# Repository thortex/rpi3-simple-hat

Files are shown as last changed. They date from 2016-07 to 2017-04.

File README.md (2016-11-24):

# 40-pin RPis Simple Hats

Simple Hats for 40-pin Raspbery Pi models.

## GPIO_LCD_HD44780

This hat includes the following devices:

1. three push switches.
2. three LEDs.
3. five DIP switches.
4. four I2C bus pin headers.
5. one HD44780-compatible LCD interface.
6. one CPU fan connector.
7. one UART bus pin header.

## HW-PWMx2
 
This hat includes the following interfaces:

1. Two hardware PWM controlled servo motor connectors.
2. A CPU fan connector.

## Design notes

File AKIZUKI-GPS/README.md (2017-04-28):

# 秋月電子通商製 GPS の接続方法

秋月電子通商より発売されている みちびき対応 GPS を
取り付ける方法を解説します（簡単です）。

## 必要な部材

必要な部材は本体とケーブルの二つだけです。

* [本体](http://akizukidenshi.com/catalog/g/gK-09991/)
* [ケーブル](http://akizukidenshi.com/catalog/g/gC-09731/)

## 初期設定

* ※ GPSを接続する前に行います。
* UART (serail) を有効にする必要があります。
* ※ OnChip Bluetooth の有無により、設定が異なります。

### 前提条件

Kernel は 4.4.x 〜 4.9.x 程度と仮定します。
パッケージ類は最新であると仮定します。

     $ sudo apt-get update
     $ sudo apt-get upgrade
     $ sudo rpi-update

### OnChip Bluetooth 未搭載モデル

UART (serial) を raspi-config で有効にする必要があります。

    $ sudo raspi-config

「5 Interfacing Options」を選択します。

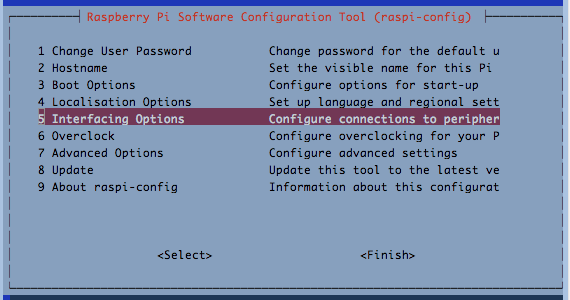
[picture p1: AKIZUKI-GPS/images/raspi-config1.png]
設定1


「P6 Serial」を選択します。

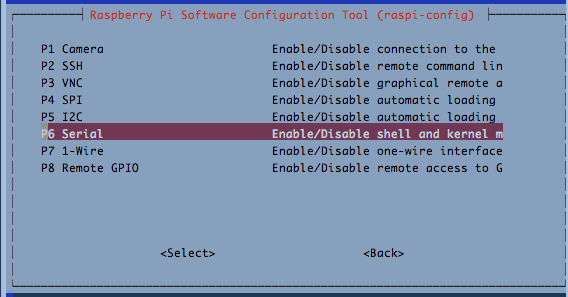
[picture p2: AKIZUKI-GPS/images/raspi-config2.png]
設定2


「Would you like a login shell to be acessible over serial?」と聞かれますが、
コンソールログインは使用しませんので「いいえ」を選択します。
「はい」を選択してしまうと、GPS側にコンソール（起動ログ等の）文字列が出力
されてしまい、誤動作する可能性があります。

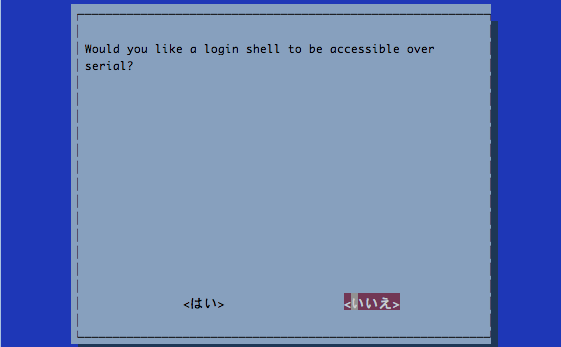
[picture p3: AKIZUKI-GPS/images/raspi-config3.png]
設定3


「Would you like to serial port hardware to be enabled?」と聞かれますので、
「はい」を選択します。

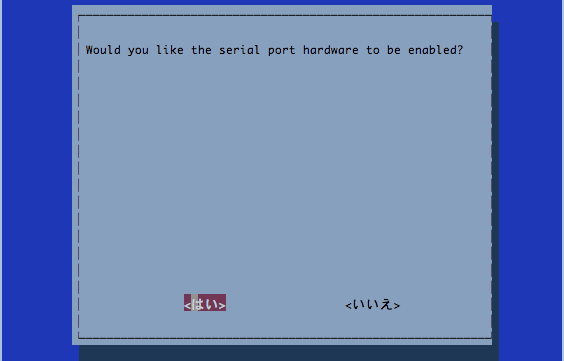
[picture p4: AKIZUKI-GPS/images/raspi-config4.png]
設定4


確認画面が表示されるので、「了解」を選択します。

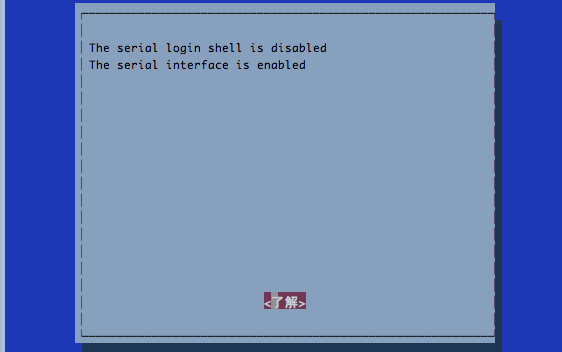
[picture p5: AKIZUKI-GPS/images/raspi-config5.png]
設定5


「Finish」を選択し、raspi-config を終了します。

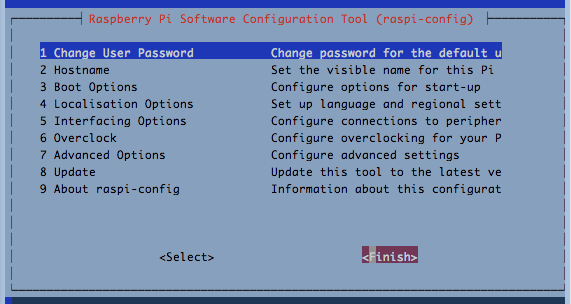
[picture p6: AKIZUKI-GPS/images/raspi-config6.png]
設定6


再起動を促されますが、一度電源を切り、GPS を接続します。

     $ sudo poweroff

### OnChip Bluetooth 搭載モデル (RPi3, RPi0W)

OnChip Bluetooth がついている RPi3, RPi0W は Bluetooth に PL011 UART
が、Serial に mini UART がデフォルトで割り当てられており、
CPU動作周波数変動に伴うコアクロック変動の影響で、mini UART の
ボーレートが一定になりません。これでは通信が安定しないため、
ペリフェラルのコアクロックを 250 MHz に固定化する必要があります。

RPi には 2 種類の UART ペリフェラルが存在します。
一つは低機能版の mini UART、もう一方は高機能版の PL011 UART です。

dtoverlay 機能により Bluetooth に PL011 UART を割り当てるか、Serial 
に PL011 UART を割り当てるかを選択する事ができます。

単純に Bluetooth を無効化し、PL011 UART を Serial に割り当てるには
以下の設定を /boot/config.txt に追加します。

     dtoverlay=pi3-disable-bt

Bluetooth に mini UART、Serial に PL011 UART を割り当てる場合は、
以下の設定を /boot/config.txt に追加します。

     dtoverlay=pi3-miniuart-bt

Bluetooth を無効にすると不便な場合もあると思いますので、
Serial に mini UART、Bluetooth に PL011 UART を割り当て、コアクロックを
250 MHz に固定化する場合、以下の設定を /boot/config.txt に追加します。

     core_freq=250

あとは「OnChip Bluetooth 未搭載モデル」の場合と同様に、raspi-config 
で Serial UART 機能を有効化します。

## 接続方法

本体側は赤枠のピンに青、緑、黄、橙、赤、茶の順番で接続します。

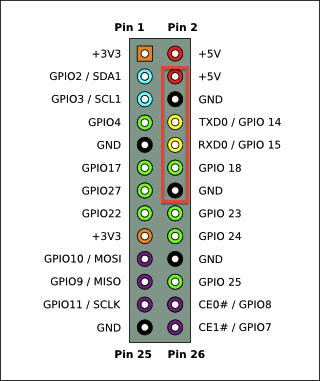
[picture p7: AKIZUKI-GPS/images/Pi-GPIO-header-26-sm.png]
本体 本体側


RPi1b, RPi2, RPi3, RPi0, RPi0W で共通のピン配置のはずです。
RPi1 の Rev. 1 だけは Pin 4 に +5V が来ていないかもしれません。

GPS 側は 5V, GND, RxD, TxD, 1PPS に青、緑、黄、橙、赤、茶の順番で接続します。
茶のピンは使用（接続）しません。

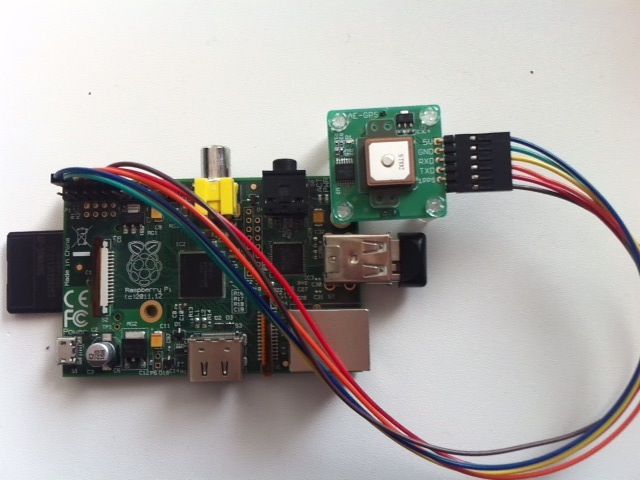
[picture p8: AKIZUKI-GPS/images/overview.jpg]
全体


## 動作確認

/dev/serial0 を head して、$GPGGA や GPGSA 等で始まる行が表示されていれば、
正常に動作していると判断できます。

     $ sudo head /dev/serial0 | strings 

下記は位置決めに必要な衛星が捕捉出来ていない状態のログです。

     $GPGGA,122708.288,,,,,0,3,,,M,,M,,*47
     $GPGSA,A,1,,,,,,,,,,,,,,,*1E
     $GPRMC,122708.288,V,,,,,0.07,143.30,090417,,,N*48
     $GPZDA,122708.288,09,04,2017,,*53
     $GPGGA,122708.288,,,,,0,3,,,M,,M,,*47
     (?$GPGSA,A,1,,,,,,,,,,,,,,,*1E

### gpsd + gpsmon による確認

gpsd をインストールすると、Serial 経由の GPS 情報を解析し、localhost:2947
で GPS 位置情報を取得できるようになります。apt-get で gpsd と clients を
インストールします。

     $ sudo apt-get install gpsd gpsd-clients

等として gpsmon とすれば、GPS の捕捉情報が取得できると思います。

/dev/serial0 を入力デバイスとして設定するため、 /etc/default/gpsd ファイル
の DEVICES という行を以下のように編集します。

     DEVICES="/dev/serial0"

編集後、gpsd を再起動し、起動状態を確認します。

     $ sudo systemctl restart gpsd.service
     $ sudo systemctl status gpsd.service

以下のように Loaded が loaded、Active が active (running) になって
いれば正常に起動しています。

     ● gpsd.service - GPS (Global Positioning System) Daemon
        Loaded: loaded (/lib/systemd/system/gpsd.service; static)
        Active: active (running) since 日 2017-04-09 20:22:32 JST; 1h 12min ago
      Main PID: 824 (gpsd)
        CGroup: /system.slice/gpsd.service
                └─824 /usr/sbin/gpsd -N /dev/serial0

正常起動を確認したら、 gpsmon コマンドを起動し、衛星が捕捉できているかを
確認します。

     $ gpsmon

起動ログ例を以下に示します。

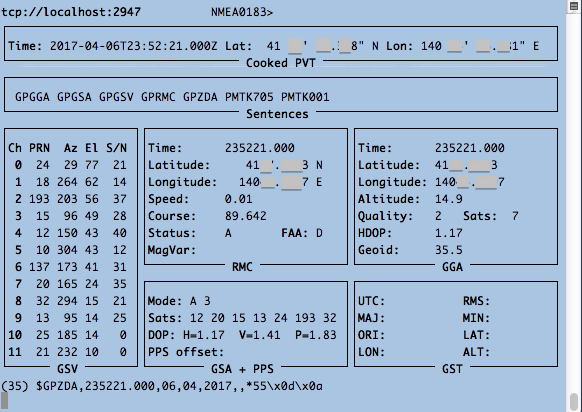
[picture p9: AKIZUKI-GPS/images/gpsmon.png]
gpsmon


捕捉衛星数が三つだと正確な位置情報が取得できません。
四つ以上捕捉出来ている状態で正確な位置情報が取得出来ていると思われます。

捕捉衛星数は 右中央の「GGA」にある「Sats」という項目の値です。

条件が良ければ屋内でも 4 衛星を捕捉可能だと思います。

他にも有益なコマンドがいくつかあります。

* xgps - X 上で gpsd の動作確認する簡易クライアント。
* xgpsspeed - GPS 情報による速度計。
* gegps - Google Earth に位置情報を送る。
* gpsctl - GPS の設定。
* gpspipe - gpsd の出力情報をパイプする。
* gpxlogger - トラッキング情報の保存。
* lcdgps - 4x40 LCD に表示する。

### 1 PPS の使用方法

Kernel の再コンパイルをしている例も他のウェブサイトでありますが、
少なくとも 4.4.x 以降の Kernel であれば、1PPS に対応しています。

/boot/config.txt に以下の行を追加します。

     dtoverlay=pps-gpio,gpiopin=18

信号の立ち下がりで PPS 信号を検知したい場合は、assert_falling_edge
を指定します。デフォルトは信号の立ち上がり検知です。

### NTP との連携

T.B.D (chronyd, ntpd)

# Navit

Navit はフリーの地図表示アプリケーションです。
GPS との連携も可能です。ルート案内も可能です。

## インストール

apt-get で navit と maptool を指定します。

     sudo apt-get install maptool navit

## フォント設定

デフォルトの状態だとフォントは Liberation Sans が選択されていますので、
日本語フォントに変更します。    

    $ sudo apt-get install fonts-takao fonts-takao-gothic
    $ mkdir -p ~/.navit/
    $ cp /etc/navit/navit.xml ~/.navit/
    $ cd ~/.navit/
    $ perl -pi.bak -e 's/<(layout) (.*?) (font=.*?)>/<$1 $2>/; s/<(layout) (.*?)>/<$1 $2 font="Takaoゴシック">/;' navit.xml

フォント名は LANG に合わせる必要があります。LANG=C の場合は、"Takao Gochic"
や "TakaoGothic"、LANG=ja_JP.UTF-8 の場合は fontconfig 上でのフォント名が
"Takaoゴシック" になります。

## 地図データのダウンロード

地図は OpenStreetMap データが使用可能です。
http://download.geofabrik.de/asia/japan.html のサイトから japan-latest.osm.bz2
をダウンロードし、maptool で navit 用ファイルに変換する方法があります。

     $ mkdir -p ~/navit
     $ cd ~/navit
     $ wget -c http://download.geofabrik.de/asia/japan-latest.osm.bz2
     $ bzcat japan-latest.osm.bz2 | maptool -S 100000000 japan.bin

変換には長い時間がかかります。すでに navit 用に変換済みのファイルを
ダウンロードする事も可能です。

http://maps3.navit-project.org/ のサイトで
「Predefined Area」→「Asia」→「Japan+Korea+Taiwan」を選択し、
「Get map!」ボタンをクリックする事で navit 用の地図ファイルを
ダウンロード可能です。

CLI から直接矩形領域を指定してダウンロードする事も可能です。

     $ cd ~/navit
     $ wget -O japan-all.bin -c 'http://maps3.navit-project.org/api/map/?bbox=117.6,20.5,151.3,47.1'

ダウンロードしたファイルは japan-all.bin として ~/navit 配下に保存されていると
仮定します。

OpenStreetMaps の地図情報を有効にするため、~/.navit/navit.xml を編集します。

     $ vi ~/.navit/navit.xml

以下の行を探します。

      <!-- Mapset template for openstreetmaps -->
       <mapset enabled="no">
        <map type="binfile" enabled="yes" data="/media/mmc2/MapsNavit/osm_europe.bin"/>
       </mapset>

以下のように書き換えます。

      <!-- Mapset template for openstreetmaps -->
       <mapset enabled="yes">
        <map type="binfile" enabled="yes" data="/home/pi/navit/japan-all.bin"/>
       </mapset>

無効な mapset が enabled になっていると、正常に地図情報が表示できないため、
デフォルトの navit.xml で enabled が "yes" になっている mapset を
disabled にします。

               <mapset enabled="yes">
                       <xi:include href="$NAVIT_SHAREDIR/maps/*.xml"/>
               </mapset>

以下のようにします。

               <mapset enabled="no">
                       <xi:include href="$NAVIT_SHAREDIR/maps/*.xml"/>
               </mapset>

## 起動

デスクトップマネージャーのアプリケーションメニューにも Navit が追加されて
いると思います。Navit のアイコンをクリックするだけで起動可能だと思います。
この場合、~/.navit 配下の navit.xml を /etc 側にコピーすると、設定が
システム全体に反映されます。

     $ sudo cp ~/.navit/navit.xml /etc/navit/

ターミナルから起動する場合は、以下のように設定ファイルを指定して起動する
ことが可能です。

     $ navit -c ~/.navit/navit.xml

## GUI の変更

デフォルトだと internal GUI が選択されますが、GTK+ GUI の I/F を表示
したければ、追加で以下のパッケージをインストールし、navit.xml で
gui の選択を行います。

     $ sudo apt-get install navit-gui-gtk

## ボタン類の表示

デフォルト設定でinternal に GUI を選択していると、ボタン類が表示されませんので、

     <osd enabled="no"

という行を "yes" に変更することで、操作ボタン類が表示されるようになります。

## 日本語化

日本人の開発者が少ないのか、メッセージの日本語化が十分ではありません。

本家に PR しているので、取り込まれる可能性はありますが、
私家版の日本語化メッセージファイルを以下に配置しています。

https://github.com/thortex/navit/raw/thortex/thortex/navit.mo

日本語化ファイルの差し替え手順は以下です。
まず、オリジナルのファイルを .old に修正しておきます。

     $ sudo mv /usr/share/locale/ja/LC_MESSAGES/navit.mo \
               /usr/share/locale/ja/LC_MESSAGES/navit.mo.old

私家版日本語化ファイルをダウンロードします。

     $ wget https://github.com/thortex/navit/raw/thortex/thortex/navit.mo

コピーします。

     $ sudo cp navit.mo /usr/share/locale/ja/LC_MESSAGES/navit.mo

自分で好きなように日本語化する事が可能です。

po/ja.po.in ファイルか thortex/ja.po.in ファイルを編集し、msgfmt
コマンドでバイナリに変換します。

     $ msgfmt -o navit.mo ja.po.in

元になるファイルは本家の github か以下に存在します。

https://github.com/thortex/navit/tree/thortex/thortex

## Navit Configurator

navit.xml を編集する GUI ツールとして Navit Configurator があります。

* http://wiki.navit-project.org/index.php/NavitConfigurator

Wiki に記載されている手順は古いので、そのまま手順を実行するとエラーになります。

* https://sourceforge.net/p/navitconfigurat/wiki/Wiki%20for%20NavitConfigurator/
* https://sourceforge.net/p/navitconfigurat/wiki/Wiki%20for%20NavitConfigurator/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

2017年現在、Jessie では以下のような手順でビルドすると成功します。

     $ udo apt-get install qtbase5-dev qttools5-dev-tools libqt5webkit5-dev qt5-qmake qt5-default
     $ git clone http://git.code.sf.net/p/navitconfigurat/code navitconfigurat-code
     $ cd navitconfigurat-code
     $ qmake
     $ make
     $ sudo checkinstall

または

     $ sudo make install

qmake の Qt バージョンが 4.x.x 系ではなく 5.x.x 系になっている事が必要です。

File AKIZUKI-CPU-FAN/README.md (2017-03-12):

# 秋月 Raspberry Pi 用ユニバーサル基板と25mm角ファン 

RPi3 は 高負荷で長時間連続稼動させると、
CPU温度及び周辺温度が高温になると思います。

秋月電子より発売されている RPi用ユニバーサル基板を
ドリルで多少改造し、5V 25mm 角 DC ファンを取り付けるだけで、
結構放熱されるようです。

CPUにヒートシンクが取り付けられている
場合は干渉する可能性があります。

## 加工方法の概要
PDF 参照。

## 加工方法詳細

### ドリルで穴あけ
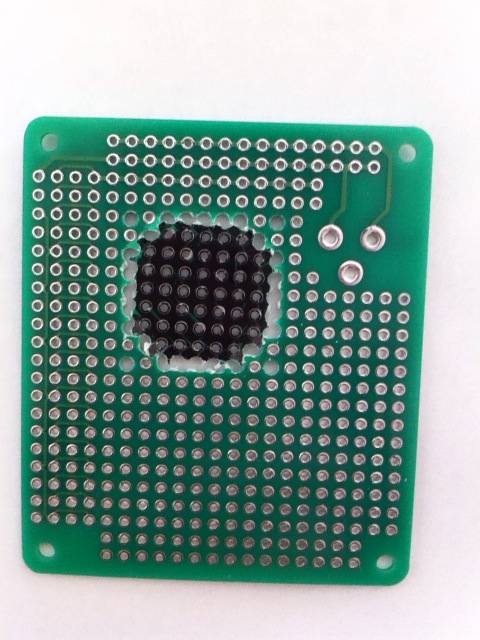
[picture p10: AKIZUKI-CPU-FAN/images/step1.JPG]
Step 1
 
 
### ペンチで切断
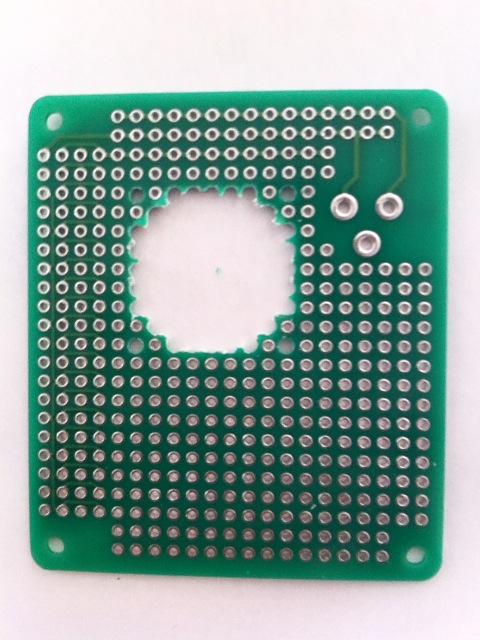
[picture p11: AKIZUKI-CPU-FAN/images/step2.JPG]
Step 2
 
 
### ヤスリ掛け
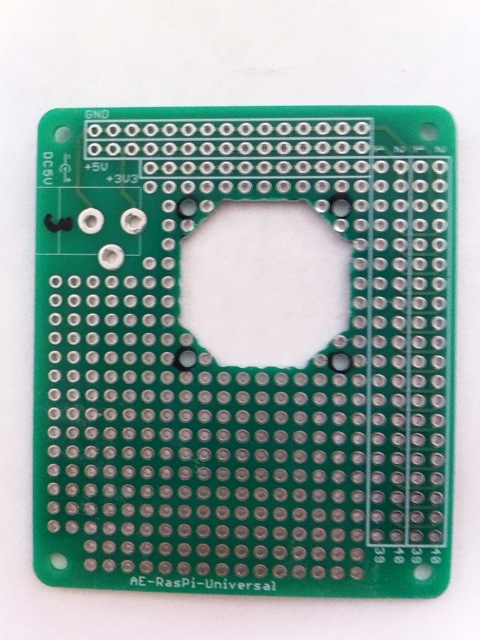
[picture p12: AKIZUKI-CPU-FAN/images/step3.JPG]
Step 3
 
 
### M2x15mm と M3 ナット取り付け
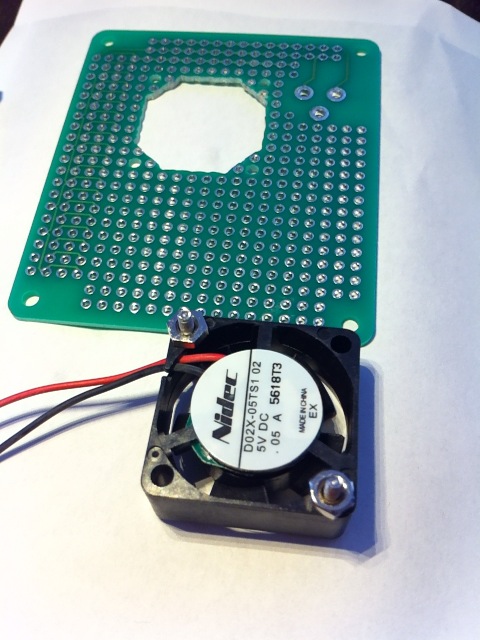
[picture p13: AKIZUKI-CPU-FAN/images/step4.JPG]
Step 4
 
 
### M2 ナットで取り付け
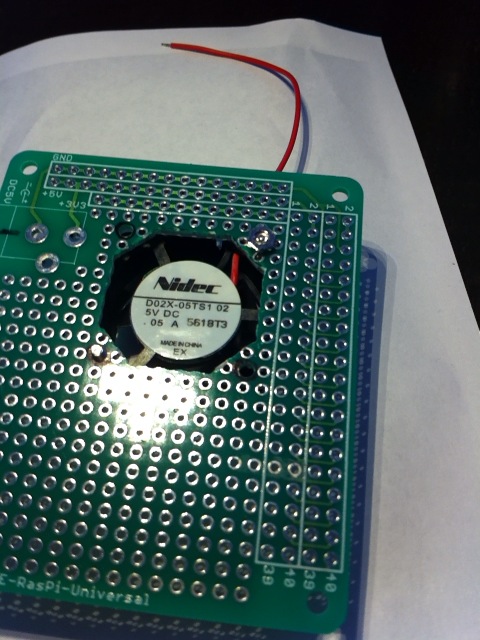
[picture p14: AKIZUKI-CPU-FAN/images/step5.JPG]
Step 5
 

## 部品 

* http://akizukidenshi.com/catalog/g/gP-11073/ (\150)
* http://akizukidenshi.com/catalog/g/gC-10702/ (\150)
* http://akizukidenshi.com/catalog/g/gC-09408/ (\30)
* http://akizukidenshi.com/catalog/g/gM-06238/ (\1,000)
* http://akizukidenshi.com/catalog/g/gP-02480/ (\100)

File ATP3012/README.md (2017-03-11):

# RPi から ATP3012 を制御するための基板

40-pin GPIO RPi から UART 経由で ATP3012 を制御するための基板です。

## 部品リスト

主要なものだけリストアップしています。抵抗・コンデンサは適当に揃えてください。

| 記号 | 説明 |  価格  | URL  | 
| ---- | ---- |  ----  | ---- |
| SV1  | 基板 | \150 | http://akizukidenshi.com/catalog/g/gP-11073/ |
| | コネクタ | \150 | http://akizukidenshi.com/catalog/g/gC-10702/ |
| | DCジャック | \30 | http://akizukidenshi.com/catalog/g/gC-09408/ |
| | 5V 4A 電源 | \1,000 | http://akizukidenshi.com/catalog/g/gM-06238/ |
| | 5V 25mm Fan  | \100 | http://akizukidenshi.com/catalog/g/gP-02480/ |
| IC1  | FXMA108 | \250 | http://akizukidenshi.com/catalog/g/gM-04522/ |
| | IC1 ソケット | \100 | http://akizukidenshi.com/catalog/g/gP-00009/ |
| IC2  | ATP3012 | \900 | http://akizukidenshi.com/catalog/g/gI-06218/ |
| | または | | http://akizukidenshi.com/catalog/g/gI-09973/ |
| | または | | http://akizukidenshi.com/catalog/g/gI-11517/ |
| | IC2 ソケット | \200 | http://akizukidenshi.com/catalog/g/gP-00013/ |
| Q4 | 2SA1015 | \100 | http://akizukidenshi.com/catalog/g/gI-00882/ |
| SV2  | TPA2006 | \300 | http://akizukidenshi.com/catalog/g/gK-08161/ |
| | SV2 ソケット | \30 | http://akizukidenshi.com/catalog/g/gC-03785/ |
| Q1 | 16 MHz発振子 | \35 | http://akizukidenshi.com/catalog/g/gP-09576/ |
| R5 | 50k VR | \40 | http://akizukidenshi.com/catalog/g/gP-03281/ |

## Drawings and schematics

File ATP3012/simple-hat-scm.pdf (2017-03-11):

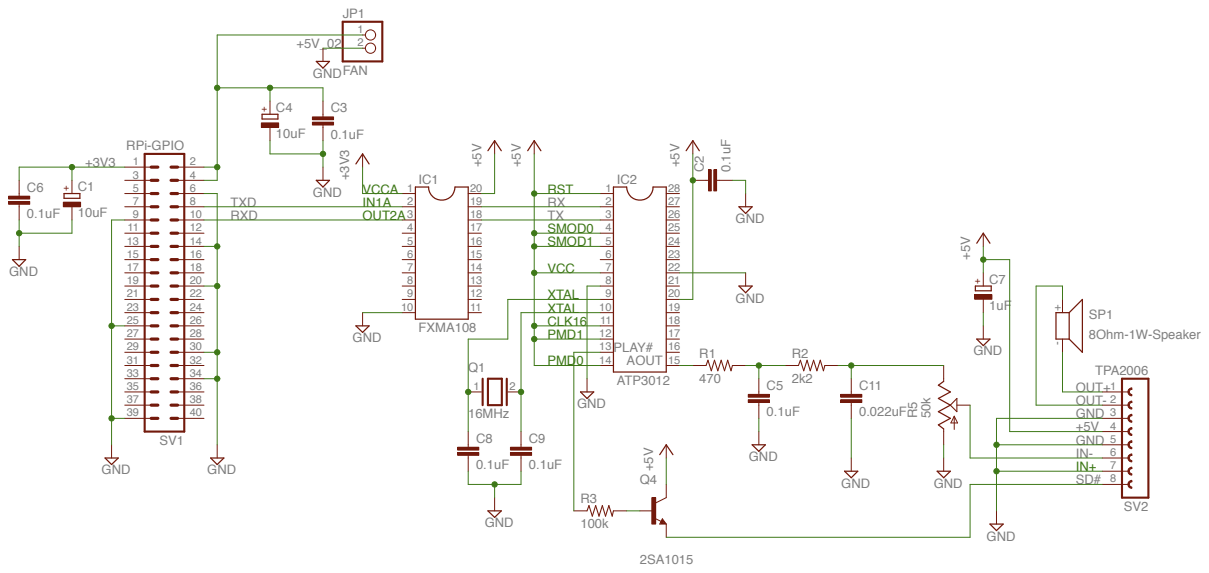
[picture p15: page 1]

18 | TX 3
17 | SMOD0 4

CLK16 | 11
PMD1 | 12

Q1 | | PMD0 | 13

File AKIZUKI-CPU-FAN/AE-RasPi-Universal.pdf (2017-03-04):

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

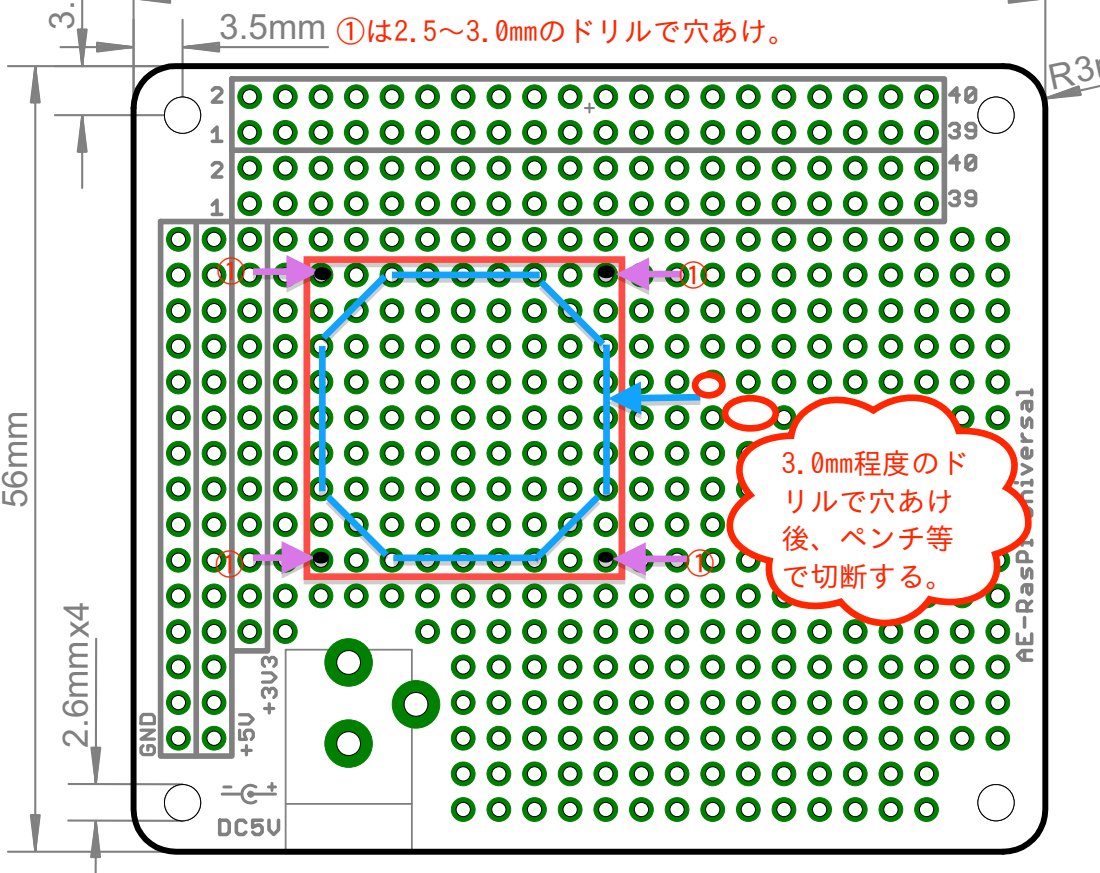
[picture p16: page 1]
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

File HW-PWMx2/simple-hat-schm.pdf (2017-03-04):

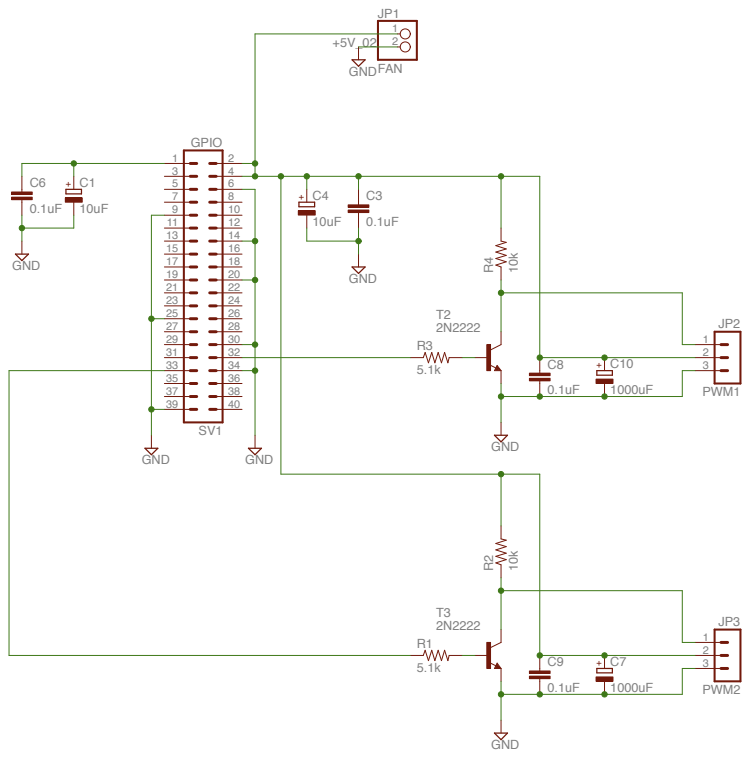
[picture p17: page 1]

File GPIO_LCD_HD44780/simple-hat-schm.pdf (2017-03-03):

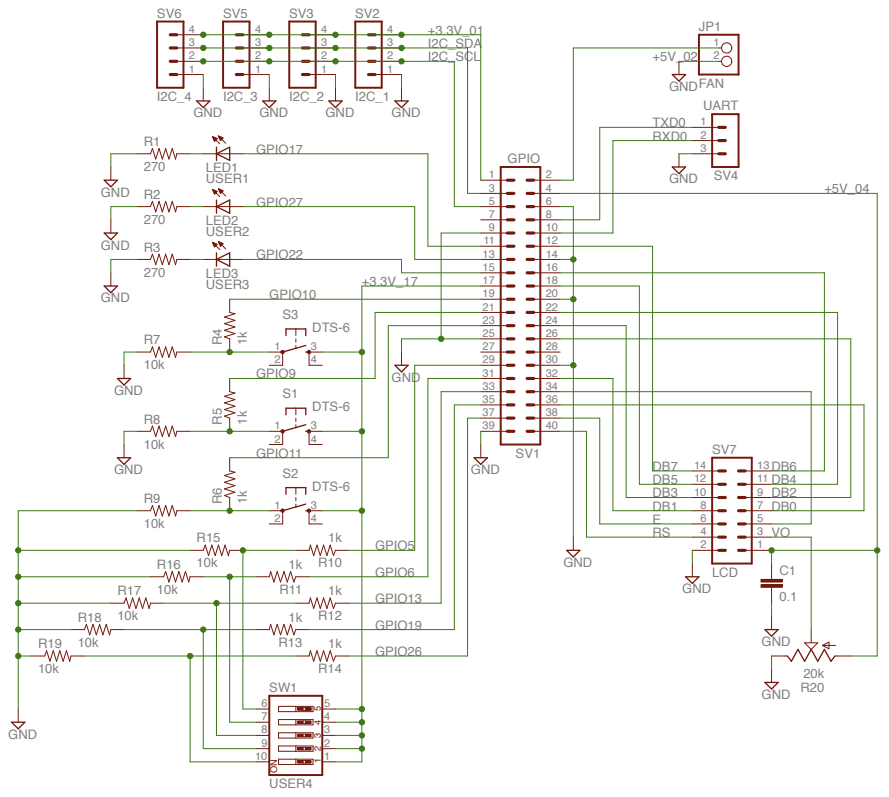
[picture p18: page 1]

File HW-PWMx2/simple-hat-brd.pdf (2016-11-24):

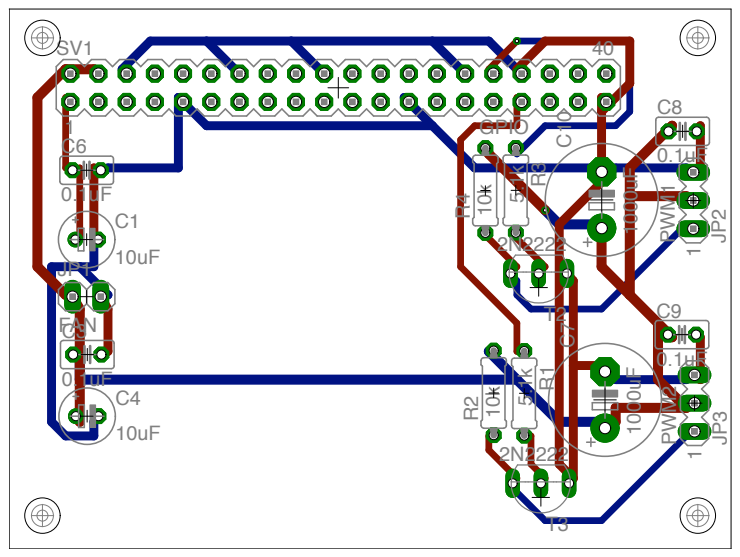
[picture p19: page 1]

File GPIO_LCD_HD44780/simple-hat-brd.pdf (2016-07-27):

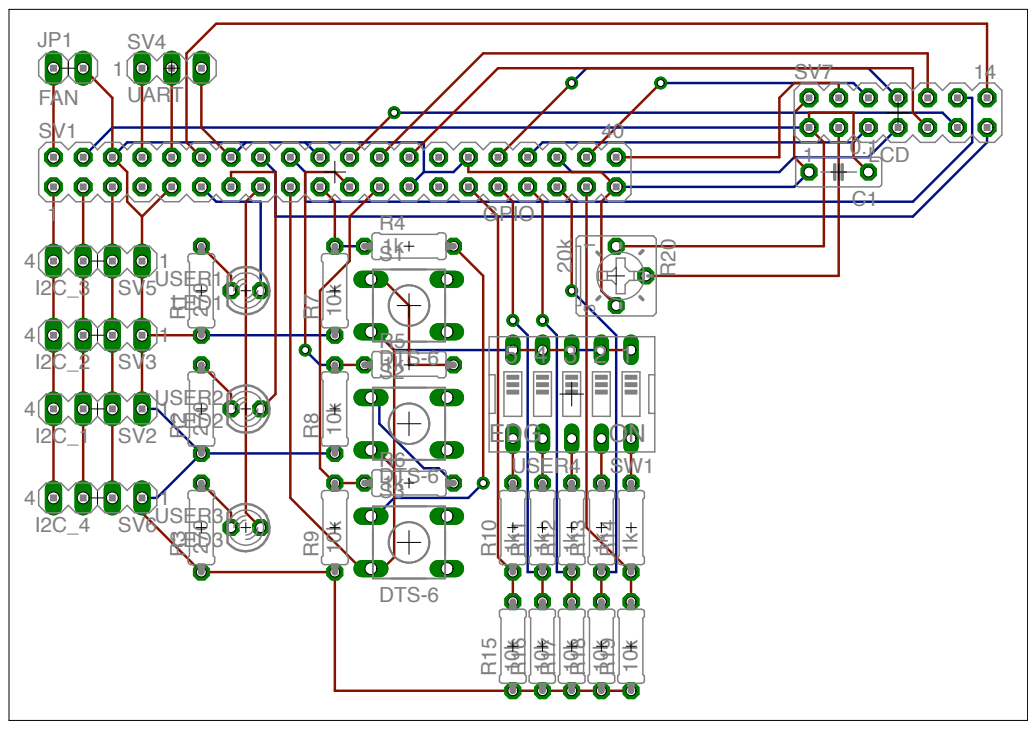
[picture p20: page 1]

DTS-6 1k | 5 | 4 | 3 | 2 | 1

R6
DTS-6 1k

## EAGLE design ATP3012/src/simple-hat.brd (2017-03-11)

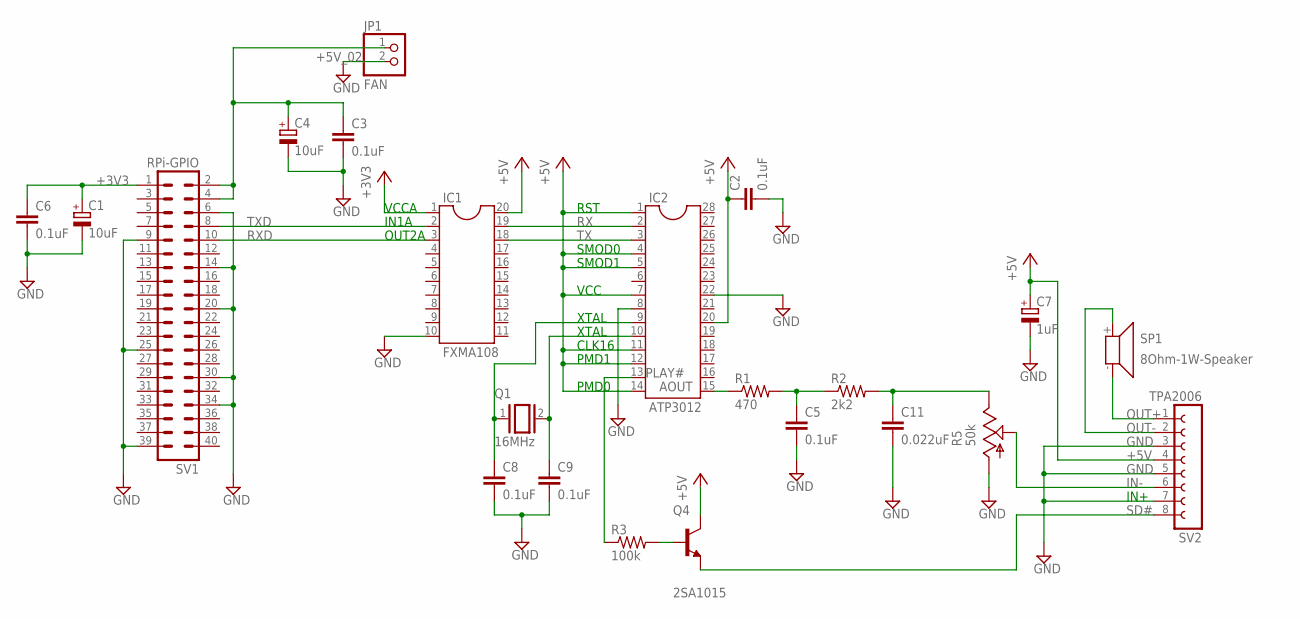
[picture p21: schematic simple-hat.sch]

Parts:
C1, C4: 10uF; E2-5
C2, C3, C5, C6, C8, C9: 0.1uF; C025-025X050
C7: 1uF; E5-10,5
C11: 0.022uF; C025-025X050
IC1: FXMA108; SOCKET-20
IC2: ATP3012; DIL28-4
JP1: FAN; 1X02
Q1: 16MHz; Q
Q4: 2SA1015; TO92-EBC
R1: 470; 0207/7
R2: 2k2; 0207/7
R3: 100k; 0207/7
R5: 50k; B25P
SP1: 8Ohm-1W-Speaker; SMS-1308MS-2-R
SV1: RPi-GPIO; MA20-2
SV2: TPA2006; FE08W

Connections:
+3V3: C1.+, C6.1, IC1.1, SV1.1
+5V: C2.1, C7.+, IC1.20, IC2.1, IC2.4, IC2.5, IC2.7, IC2.11, IC2.12, IC2.14, IC2.20, Q4.C, SV2.4
+5V_02: C3.1, C4.+, JP1.1, SV1.2, SV1.4
GND: C1.-, C2.2, C3.2, C4.-, C5.2, C6.2, C7.-, C8.2, C9.2, C11.2, IC1.10, IC2.8, IC2.22, JP1.2, R5.A, SV1.6, SV1.9, SV1.14, SV1.20, SV1.25, SV1.30, SV1.34, SV1.39, SV2.3, SV2.5, SV2.7
IN-: R5.S, SV2.6
unnamed: IC2.13, R3.1
unnamed: C9.1, IC2.10, Q1.2
unnamed: C8.1, IC2.9, Q1.1
unnamed: Q4.B, R3.2
unnamed: C5.1, R1.2, R2.1
unnamed: IC2.15, R1.1
unnamed: C11.1, R2.2, R5.E
OUT+: SP1.- (2), SV2.1
OUT-: SP1.+ (1), SV2.2
RX: IC1.19, IC2.2
RXD: IC1.3, SV1.10
SD#: Q4.E, SV2.8
TX: IC1.18, IC2.3
TXD: IC1.2, SV1.8

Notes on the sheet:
IN+
VCCA
IN1A
OUT2A
RST
SMOD0
SMOD1
VCC
XTAL
CLK16
PMD1
PMD0

Board: 2 copper layers, 22 parts (0 on the bottom side), 19 nets, no tracks yet.

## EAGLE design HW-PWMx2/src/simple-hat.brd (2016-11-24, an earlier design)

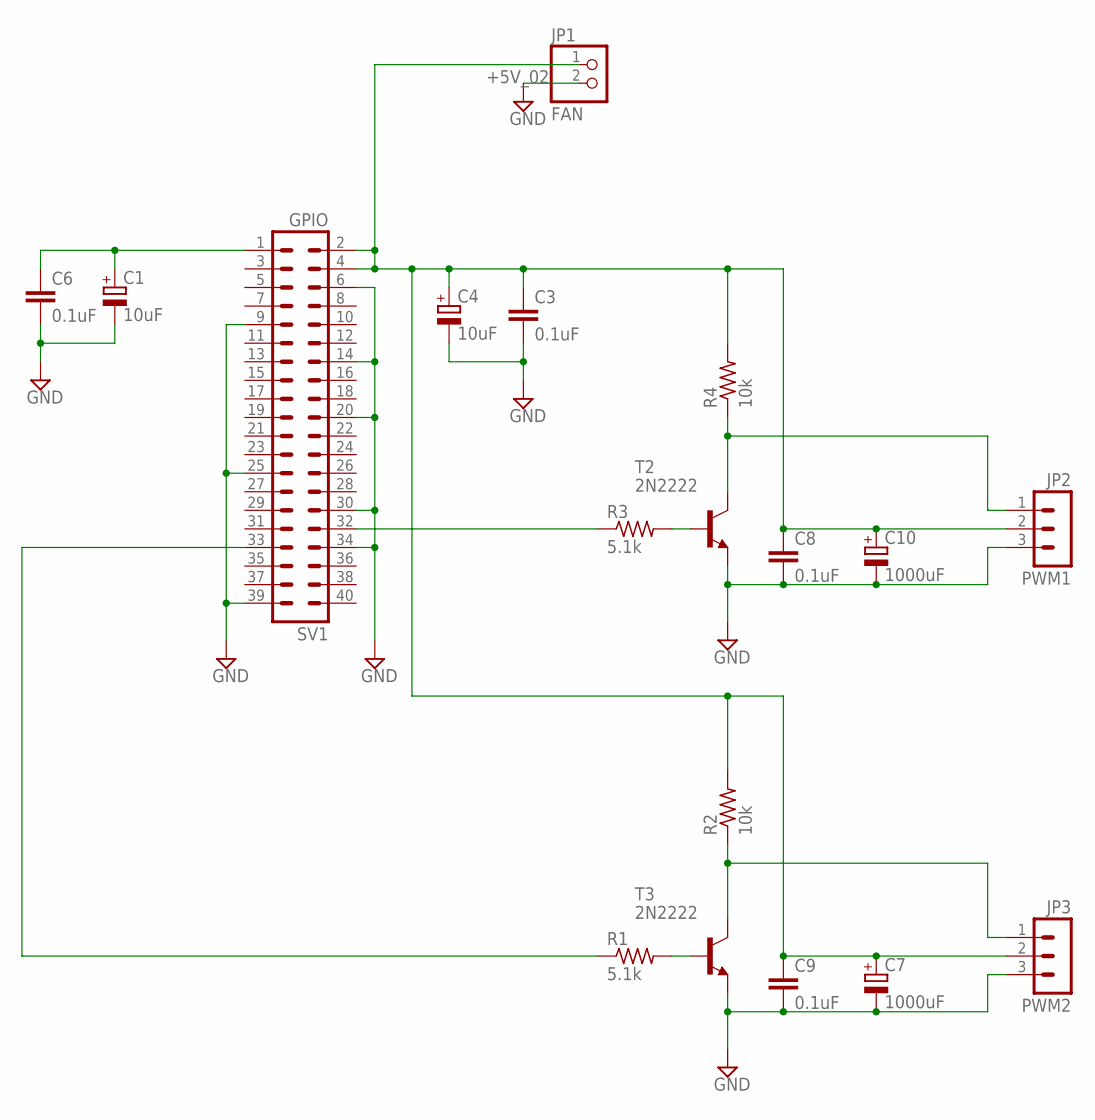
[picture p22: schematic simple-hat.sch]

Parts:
C1, C4: 10uF; E2-5
C3, C6, C8, C9: 0.1uF; C025-025X050
C7, C10: 1000uF; E5-10,5
JP1: FAN; 1X02
PWM1: JP2; MA03-1
PWM2: JP3; MA03-1
R1, R3: 5.1k; 0207/7
R2, R4: 10k; 0207/7
SV1: GPIO; MA20-2
T2, T3: 2N2222; TO92-EBC

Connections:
+5V_02: C3.1, C4.+, C7.+, C8.1, C9.1, C10.+, JP1.1, PWM1.2, PWM2.2, R2.2, R4.2, SV1.2, SV1.4
GND: C1.-, C3.2, C4.-, C6.2, C7.-, C8.2, C9.2, C10.-, JP1.2, PWM1.3, PWM2.3, SV1.6, SV1.9, SV1.14, SV1.20, SV1.25, SV1.30, SV1.34, SV1.39, T2.E, T3.E
unnamed: C1.+, C6.1, SV1.1
unnamed: R1.1, SV1.33
unnamed: R3.1, SV1.32
unnamed: R3.2, T2.B
unnamed: PWM1.1, R4.1, T2.C
unnamed: R1.2, T3.B
unnamed: PWM2.1, R2.1, T3.C

Board: 2 copper layers, 18 parts (0 on the bottom side), 9 nets, no tracks yet.

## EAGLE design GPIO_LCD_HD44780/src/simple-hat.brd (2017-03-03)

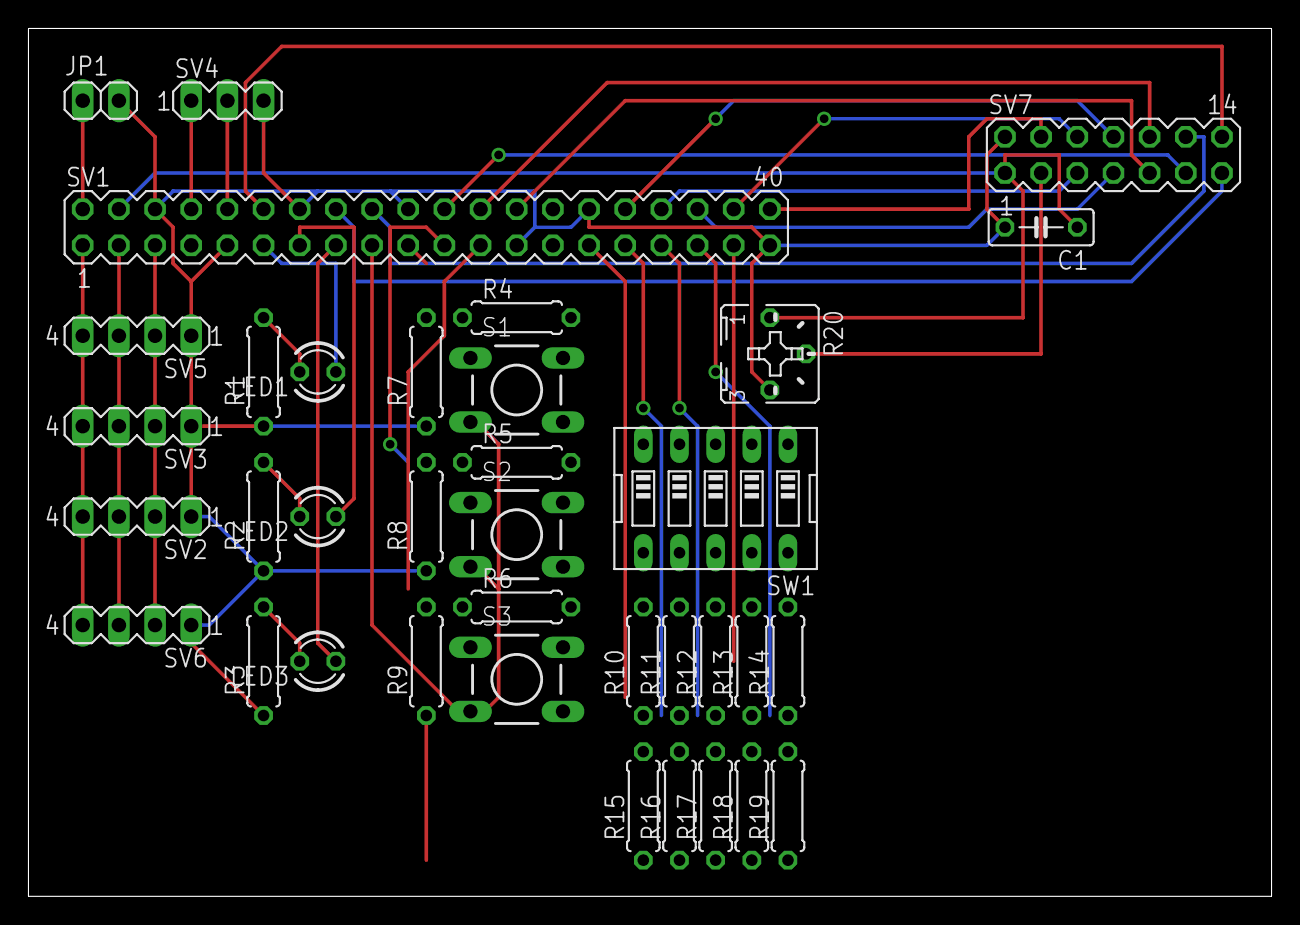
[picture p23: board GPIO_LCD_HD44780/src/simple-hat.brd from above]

Board: 2 copper layers, 87.3 x 61.0 mm, 36 parts (0 on the bottom side), 40 nets.

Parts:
C1: 0.1; C050-025X075
JP1: FAN; 1X02
LED1: USER1; LED3MM
LED2: USER2; LED3MM
LED3: USER3; LED3MM
R1, R2, R3: 270; 0207/7
R4, R5, R6, R10, R11, R12, R13, R14: 1k; 0207/7
R7, R8, R9, R15, R16, R17, R18, R19: 10k; 0207/7
R20: 20k; B25P
S1, S2, S3: DTS-6
SV1: GPIO; MA20-2
SV2: I2C_1; MA04-1
SV3: I2C_2; MA04-1
SV4: UART; MA03-1
SV5: I2C_3; MA04-1
SV6: I2C_4; MA04-1
SV7: LCD; MA07-2
SW1: USER4; EDG-05

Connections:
+3.3V_01: SV1.1, SV2.4, SV3.4, SV5.4, SV6.4
+3.3V_17: S1.3, S2.3, S3.3, SV1.17, SW1.1, SW1.2, SW1.3, SW1.4, SW1.5
+5V_02: JP1.1, SV1.2
+5V_04: C1.1, R20.A, SV1.4, SV7.1
DB0: SV1.36, SV7.7
DB1: SV1.32, SV7.8
DB2: SV1.26, SV7.9
DB3: SV1.24, SV7.10
DB4: SV1.22, SV7.11
DB5: SV1.18, SV7.12
DB6: SV1.16, SV7.13
DB7: SV1.12, SV7.14
E: SV1.38, SV7.6
GND: C1.2, JP1.2, R1.1, R2.1, R3.1, R7.1, R8.1, R9.1, R15.1, R16.1, R17.1, R18.1, R19.1, R20.E, SV1.6, SV1.9, SV1.14, SV1.20, SV1.25, SV1.30, SV1.39, SV2.1, SV3.1, SV4.3, SV5.1, SV6.1, SV7.2
GND34: SV1.34, SV7.5
GPIO5: R10.1, SV1.29
GPIO6: R11.1, SV1.31
GPIO13: R12.1, SV1.33
GPIO17: LED1.A, SV1.11
GPIO19: R13.1, SV1.35
GPIO22: LED3.A, SV1.15
GPIO26: R14.1, SV1.37
GPIO27: LED2.A, SV1.13
I2C_SCL: SV1.5, SV2.2, SV3.2, SV5.2, SV6.2
I2C_SDA: SV1.3, SV2.3, SV3.3, SV5.3, SV6.3
unnamed: LED1.K, R1.2
unnamed: LED2.K, R2.2
unnamed: LED3.K, R3.2
unnamed: R4.1, R7.2, S3.1
unnamed: R5.1, R8.2, S1.1
unnamed: R6.1, R9.2, S2.1
unnamed: R10.2, R15.2, SW1.6
unnamed: R11.2, R16.2, SW1.7
unnamed: R12.2, R17.2, SW1.8
unnamed: R13.2, R18.2, SW1.9
unnamed: R14.2, R19.2, SW1.10
RS: SV1.40, SV7.4
RXD0: SV1.10, SV4.2
TXD0: SV1.8, SV4.1
VO: R20.S, SV7.3

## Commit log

2016-07-24 Added v0.0.1
    [simple-hat.brd, simple-hat.dxf, simple-hat.sch]
2016-07-27 Added routed borad data
    [simple-hat.brd, simple-hat.csv, simple-hat.dxf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]
2016-10-30 Created a sub-directory for GPIO LCD simple hat.
    [simple-hat.brd, simple-hat.csv, simple-hat.dxf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]
2016-11-19 2 channels Hardware PWM controlling board.
    [simple-hat.brd, simple-hat.csv, simple-hat.dxf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]
2016-11-24 Modified HW-PWMx2
    [simple-hat.brd, simple-hat.csv, simple-hat.dxf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]
2017-03-03 Modified GPIO_LCD circuit.
    [simple-hat.brd]
2017-03-03 Modified hardware PWM circuit.
2017-03-04 modified schematics pdf file.
2017-03-04 Added CPU Fan for AE-RPi
2017-03-11 Added RPi3-ATP3012 schem.
    [simple-hat.brd, simple-hat.sch]
